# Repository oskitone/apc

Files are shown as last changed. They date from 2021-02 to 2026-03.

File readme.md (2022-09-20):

# APC

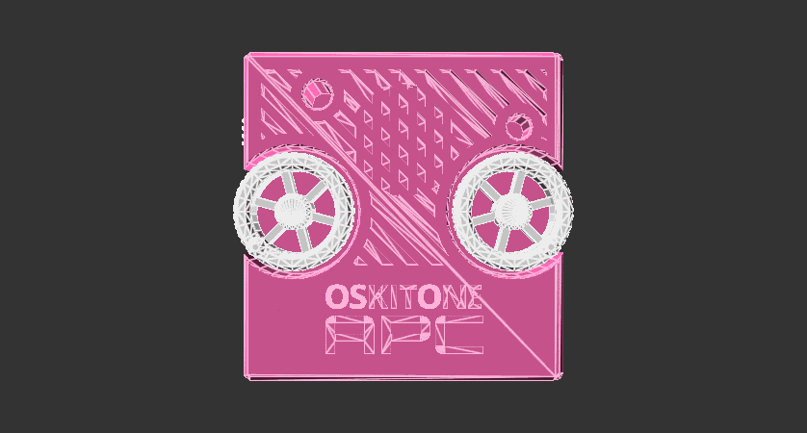
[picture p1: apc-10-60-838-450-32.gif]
APC


A decapitated robot head? An extraterrestrial communicator? A specter summoner?

Nope (and yep!), it's an [APC](https://en.wikipedia.org/wiki/Atari_Punk_Console)!

**Assembly Guide:** [https://oskitone.github.io/apc/](https://oskitone.github.io/apc/)<br />
**Demo:** [https://vimeo.com/518375593](https://vimeo.com/518375593)<br />
**Purchase:** [APC (fully assembled)](https://www.oskitone.com/product/apc), [APC DIY Electronics Kit](https://www.oskitone.com/product/apc-diy-electronics-kit)<br />
**Blog post:** [https://blog.tommy.sh/posts/oskitone-makes-an-atari-punk-console/](https://blog.tommy.sh/posts/oskitone-makes-an-atari-punk-console/)

## KiCad Source

The PCB and its schematic are actually part of [poly555](https://github.com/oskitone/poly555), so head over there to its KiCad project to dig deeper into the electronics. (That the APC is a part of a bigger project may also help to explain why the component numbers start at 100!)

## 3D Models

The APC's 3D-printed models are written in OpenSCAD.

### Changelog

- **September 6, 2021:** Add brim to switch_clutch for better DFM (2d0a1d0), Loosen wheel fit (7e2dab7)
- **February 25, 2021:** Init (8df1dc4)

### Dependencies

Assumes poly555 repo is in a sibling directory. Here's how I've got it:

    \ oskitone
        \ apc
        \ poly555

### Mods

- For pots with flatted D shafts, use `shaft_type = POT_SHAFT_TYPE_FLATTED` in the call to `wheels()` for a better fit.

### Building

STLs are generated with `make_stls.sh`. Run `./make_stls.sh -h` for full flags list.

## License

Designed by Oskitone. Please support future synth projects by purchasing from [Oskitone](https://www.oskitone.com/).

Creative Commons Attribution/Share-Alike, all text above must be included in any redistribution. See license.txt for additional details.

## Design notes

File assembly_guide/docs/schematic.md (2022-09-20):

---
id: schematic
title: Schematic
sidebar_label: Schematic
description: Oskitone APC Schematic
slug: schematic
hide_table_of_contents: true
image: /img/assembly/apc.jpg
---

APC Schematic

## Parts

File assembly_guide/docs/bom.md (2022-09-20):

---
id: bom
title: BOM (Bill of Materials)
sidebar_label: BOM
description: BOM (Bill of Materials)
slug: bom
hide_table_of_contents: true
image: /img/assembly/apc.jpg
---

| Part | Package | Quantity | Value | Marking |
| --- | --- | --- | --- | --- |
| BT101 | Battery snap | 1 | 9v | |
| C101 | Ceramic disc D5.0mm_W2.5mm_P5.00mm  | 1 | .01uF / 10nF | 103 |
| C102 | Ceramic disc D5.0mm_W2.5mm_P5.00mm  | 1 | .1uF | 104 |
| C103 | CP_Radial_D4.0mm_P2.00mm | 1 | 10uF | |
| D101 | LED D5.0mm | 1 | LED | |
| LS101 | Speaker 30mm_36MS30008-PN | 1 | Speaker | |
| R101 | Resistor | 1 | 330 | Orange Orange Brown |
| R102 | Resistor | 1 | 1k | Brown Black Red |
| RV101, RV102 | PTV09 Vertical Pot | 2 | 500k-1M | |
| RV103 | Potentiometer Piher_PT-6-V_Vertical | 1 | 1k | 102 |
| S101 | EG1218 slider switch | 2 | | |
| U101 | DIP-14_W7.62mm_LongPads | 1 | LM556 | |

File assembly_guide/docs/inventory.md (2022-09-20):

---
id: inventory
title: Inventory
sidebar_label: Inventory
description: What you'll need to assembly your APC
slug: inventory
image: /img/assembly/apc.jpg
---

## What You'll Need

- The [Oskitone APC DIY Electronics Kit](https://www.oskitone.com/product/apc-diy-electronics-kit)!
- Soldering iron and solder for electronics
- Wire stripper or cutters
- 9v battery

## Good to have

While not required, it'd be good to have these tools around too.

- Multimeter for debugging
- PCB vice or “helping hands” holder
- “Solder sucker” or desoldering braid
- Patience, patience, patience

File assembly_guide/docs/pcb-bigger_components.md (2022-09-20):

---
id: pcb-bigger_components
title: Bigger components
sidebar_label: 3. Bigger components
description: How to solder the APC's pots, speaker, and IC socket
slug: pcb-bigger_components
image: /img/assembly/apc.jpg
---

:::note
Take your time and make sure the pots and speaker are perfectly flat against the PCB before soldering all of their pins.
:::

Last is the bigger components: pots, speaker, and IC.

1. Push the two **500k pots** ("pot" is short for "potentiometer"!) into their footprints at **RV101** and **RV102**
   1. A trick to get the pot to snap in better is to _gently_ push its mounting tabs inward before popping it onto the PCB.
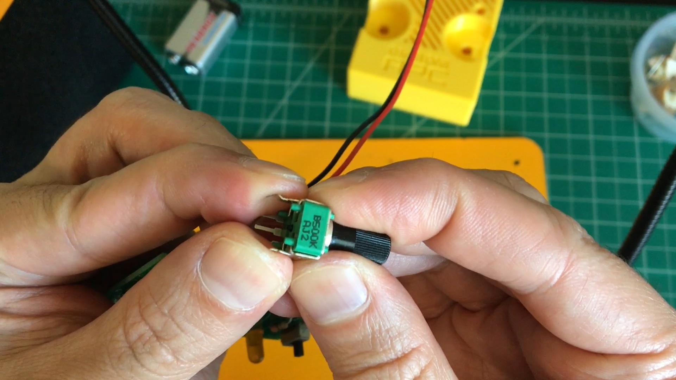
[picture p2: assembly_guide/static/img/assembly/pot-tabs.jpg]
Bending the potentiometer tabs
      
   2. Check that they're flat against the PCB, then solder into place.
   3. You can solder the mounting tabs on the side too, if you want!
2. Fit the **speaker** into **LS101**, matching its **+** and **-** pins to the right holes.
   1. Don't bend its leads! That can break it.
   2. Hold in place and solder. <!-- TODO: advise on technique -->
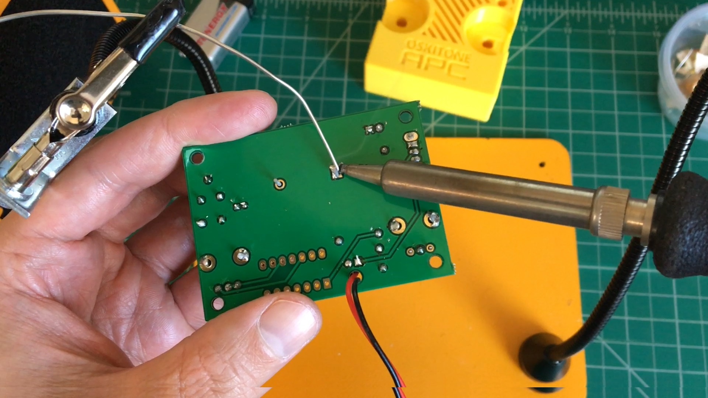
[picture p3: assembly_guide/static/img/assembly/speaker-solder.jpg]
Soldering the APC speaker at LS101
      
   3. Check that the **speaker** is flat against the PCB before continuing.
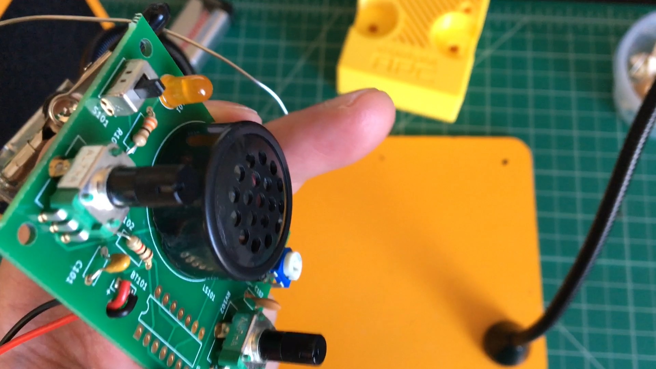
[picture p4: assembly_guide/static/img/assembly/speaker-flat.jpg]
Speaker, flat against PCB
      
3. And the absolute last component to solder is the **IC socket**
   1. Place the **IC socket** into **U101**, matching its little indentation to the footprint.
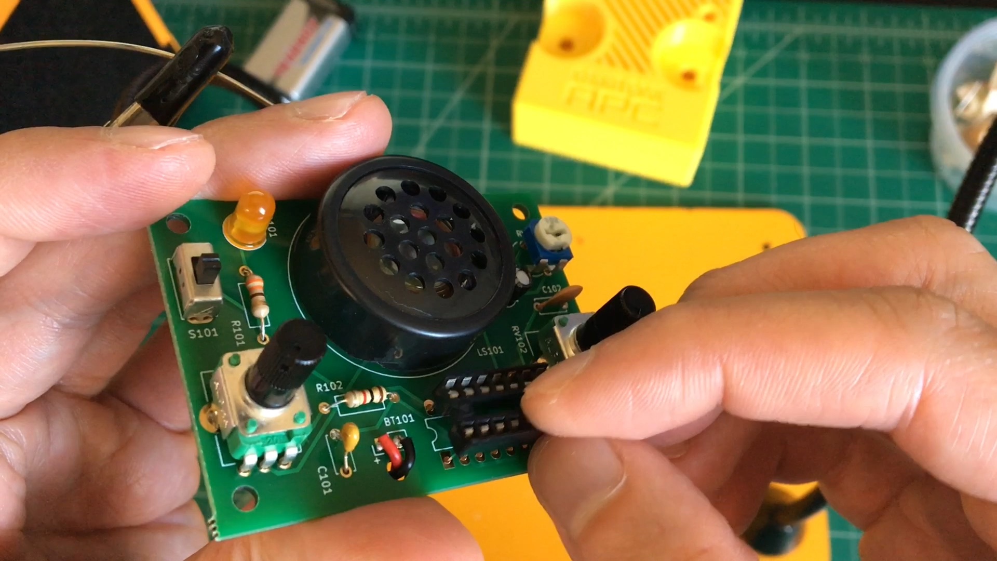
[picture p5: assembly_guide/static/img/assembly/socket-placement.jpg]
Placing the IC socket at U101
      
   2. Hold in place and solder. <!-- TODO: advise on technique -->
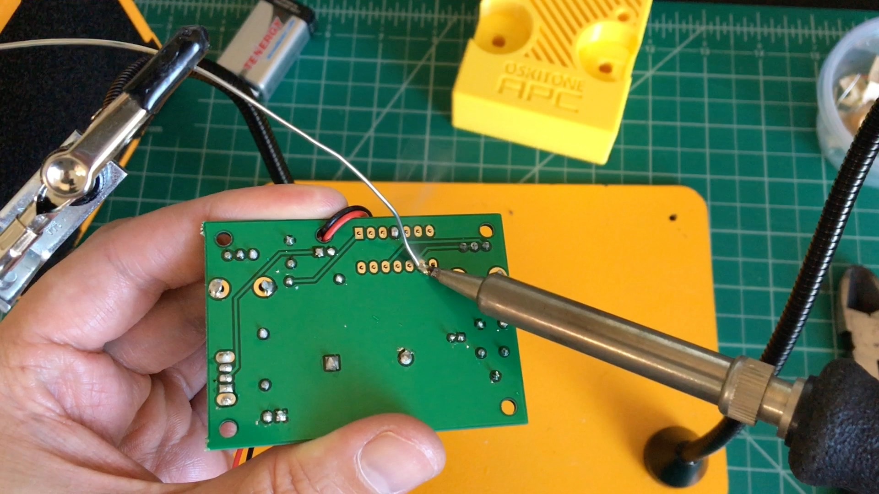
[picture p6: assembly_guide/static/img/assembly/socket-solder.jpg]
Soldering the socket
      
4. With its socket soldered, we can add its **556 chip**.
   1. In order to fit well into its **socket**, the pins of the **556** need to point straight down from the chip's body. You can use a [pin straightener tool](https://www.jameco.com/z/ICS-01-R-Jameco-Benchpro-IC-Pin-Straightener-for-0-300-and-0-600-Wide-ICs_99363.html) or simply bend them against any flat surface. <!-- TODO: advise on technique -->
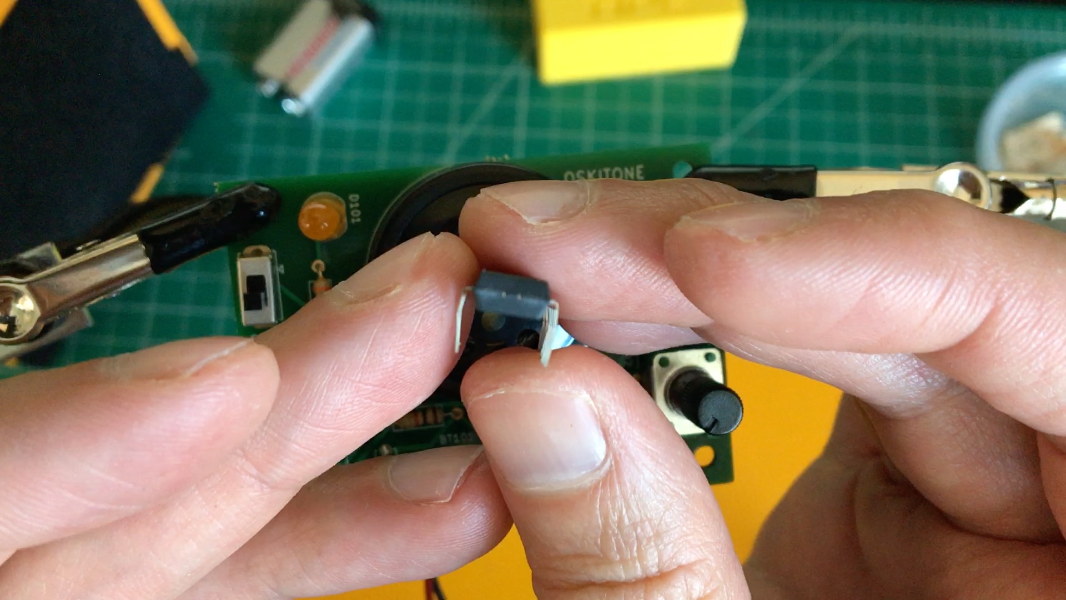
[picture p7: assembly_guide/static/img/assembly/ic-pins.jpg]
The IC chip's pins, straightened
      
   2. Carefully insert the **556 chip** into the **socket** at **U101**, matching its indentation. If its pins don't seem to go in well, try the previous step again.
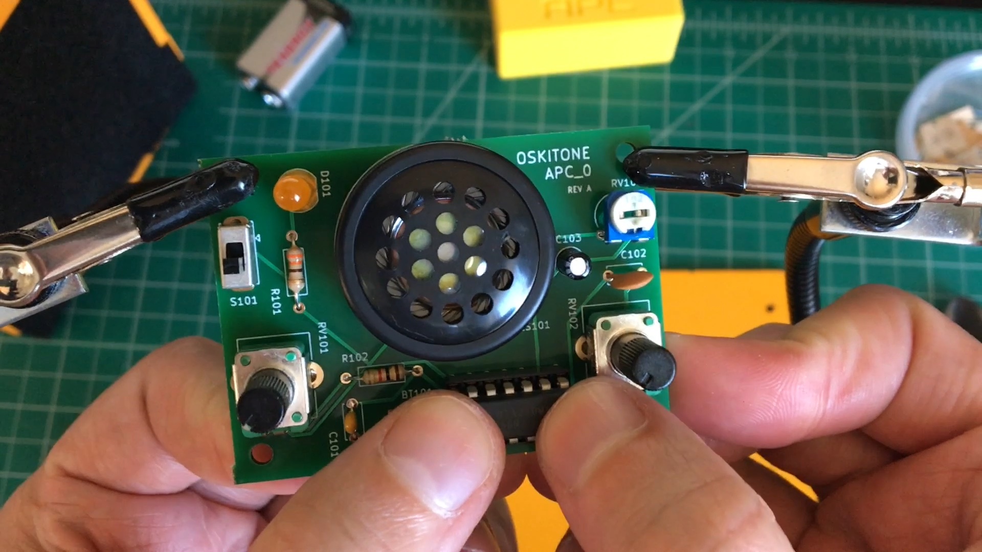
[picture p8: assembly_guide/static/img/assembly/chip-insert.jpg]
556 chip into socket at U101
      

<!-- TODO: consider breaking out test from the rest of the steps -->

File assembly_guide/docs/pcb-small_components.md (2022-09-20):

---
id: pcb-small_components
title: Small components
sidebar_label: 2. Small components
description: Soldering the APC's small components
slug: pcb-small_components
image: /img/assembly/apc.jpg
---

:::note
Take your time and make sure the 1k trim pot is perfectly flat against the PCB before soldering all of its pins.
:::

Next we'll do the remaining small, passive components.

1. There are two small ceramic capacitors:
   1. The one marked _103_ is for **.01uF** (also known as 10nF). It goes to **C101**.
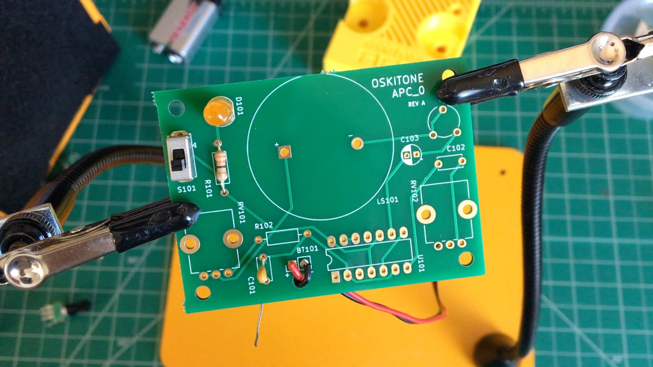
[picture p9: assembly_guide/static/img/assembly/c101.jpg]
.01uF to C101
      
   2. The other's marked _104_, for **.1uF**, and goes to **C102**.
      .1uF to C102
2. The last cap is an electrolytic **10uF** capacitor at **C103**.
   - Match the capacitor's white stripe to the white part of the footprint.
     10uF to C103
3. The remaining resistor is **1k ohms**, colored _Brown Black Red_.
   - Solder to **R102**.
     1k ohms to R102
4. The small, blue **1k trim potentiometer** goes to **RV103**. It's marked _102_. Make sure it's flat against the PCB. <!-- TODO: advise on technique -->
   - 1k trim pot to 102
5. Nothing to test here, but check all solder joints and trim leads before moving on. We're almost done!

<!-- TODO: consider breaking out test from the rest of the steps -->

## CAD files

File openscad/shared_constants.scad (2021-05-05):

// TODO: remove any includes. this file should have no dependencies...
include <battery.scad>;
include <pcb.scad>;

FIXED_LODEF_ROUNDING = 6;
DEFAULT_ROUNDING = $preview ? undef : 24;
HIDEF_ROUNDING = $preview ? undef : 120;

DEFAULT_DFM_LAYER_HEIGHT = .2;
BREAKAWAY_SUPPORT_DEPTH = .5;

DEFAULT_TOLERANCE = .1;

ENCLOSURE_WALL = 2.4;
ENCLOSURE_INNER_WALL = 1.2;
ENCLOSURE_FLOOR_CEILING = 1.8;
ENCLOSURE_INTERNAL_GUTTER = 2;
ENCLOSURE_SIDE_OVEREXPOSURE = 1.4;

ENCLOSURE_GRILL_DEPTH = 6;
ENCLOSURE_GRILL_GUTTER = 4;
ENCLOSURE_GRILL_RING = 3;
ENCLOSURE_GRILL_COVERAGE = .667;

ENCLOSURE_FILLET = 2;
ACCESSORY_FILLET = 1;

ENCLOSURE_WIDTH = PCB_WIDTH
    + ENCLOSURE_INTERNAL_GUTTER * 2
    + ENCLOSURE_WALL * 2;
ENCLOSURE_LENGTH = PCB_LENGTH
    + BATTERY_LENGTH
    + ENCLOSURE_INTERNAL_GUTTER * 3
    + ENCLOSURE_WALL * 2;

LIP_BOX_DEFAULT_LIP_HEIGHT = 3; // TODO: expose
ENCLOSURE_BOTTOM_HEIGHT = max(
    ENCLOSURE_FLOOR_CEILING + LIP_BOX_DEFAULT_LIP_HEIGHT,
    ENCLOSURE_FLOOR_CEILING + PCB_BOTTOM_CLEARANCE
);

SWITCH_CLUTCH_TOP_CLEARANCE = PCB_HEIGHT;
SWITCH_CLUTCH_SLIDE_CLEARANCE = 1.2;

MISC_CLEARANCE = 1;

PCB_X = ENCLOSURE_WALL + ENCLOSURE_INTERNAL_GUTTER;
PCB_Y = ENCLOSURE_WALL + ENCLOSURE_INTERNAL_GUTTER * 2 + BATTERY_LENGTH;
PCB_Z = max(
    ENCLOSURE_BOTTOM_HEIGHT - PCB_HEIGHT,
    ENCLOSURE_FLOOR_CEILING + PCB_BOTTOM_CLEARANCE
);

GRILL_LENGTH = (ENCLOSURE_LENGTH - ENCLOSURE_GRILL_GUTTER * 2)
    * ENCLOSURE_GRILL_COVERAGE;

// This is imperfect:
// 1) The plate is actually longer than grill.
// 2) Wheels may extend beyond grill plate.
BATTERY_FITS_BEYOND_GRILL = (ENCLOSURE_LENGTH - GRILL_LENGTH
    - ENCLOSURE_GRILL_GUTTER * 2) > BATTERY_LENGTH;

ENCLOSURE_HEIGHT =
    max(
        BATTERY_FITS_BEYOND_GRILL
            ? BATTERY_HEIGHT + ENCLOSURE_FLOOR_CEILING + BATTERY_SNAP_CLEARANCE
            : BATTERY_HEIGHT + ENCLOSURE_GRILL_DEPTH + ENCLOSURE_FLOOR_CEILING,
        PCB_Z + PCB_HEIGHT + PTV09A_POT_BASE_HEIGHT + PTV09A_POT_ACTUATOR_HEIGHT
    )
    + ENCLOSURE_FLOOR_CEILING;

ENCLSOURE_TOP_HEIGHT = ENCLOSURE_HEIGHT - ENCLOSURE_BOTTOM_HEIGHT;

Z_PCB_TOP = PCB_Z + PCB_HEIGHT;

DEFAULT_RIB_LENGTH = .8;
DEFAULT_RIB_GUTTER = 1.234;

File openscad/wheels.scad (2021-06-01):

// TODO: extract parts to common repo
use <../../poly555/openscad/lib/basic_shapes.scad>;

include <pcb.scad>;
include <shared_constants.scad>;

WHEEL_DIAMETER = 2 *
    (PCB_X + PCB_POT_POSITIONS[0][0] + ENCLOSURE_SIDE_OVEREXPOSURE);
WHEEL_VERTICAL_EXPOSURE = ENCLOSURE_SIDE_OVEREXPOSURE;
WHEEL_RECESSED_HEIGHT = 13;
WHEEL_HEIGHT = WHEEL_RECESSED_HEIGHT + WHEEL_VERTICAL_EXPOSURE;
WHEEL_DIAMETER_CLEARANCE = 1.2;
WELL_DIAMETER = WHEEL_DIAMETER + WHEEL_DIAMETER_CLEARANCE * 2;
WHEEL_RING = ENCLOSURE_FILLET * 2;

module wheel(
    diameter = WHEEL_DIAMETER,
    height = WHEEL_HEIGHT,
    ring = WHEEL_RING,

    hub_ceiling = ENCLOSURE_FLOOR_CEILING,
    hub_diameter = PTV09A_POT_ACTUATOR_DIAMETER + ENCLOSURE_INNER_WALL * 2,

    brodie_knob_diameter = WHEEL_RING,
    brodie_knob_stilt = 0,
    brodie_knob_count = 1,
    brodie_knob_angle_offset = 0,

    dimple_count = 0,
    dimple_depth = 1,
    dimple_y = undef,

    spokes_count = 6,
    spokes_width = 2,
    spokes_height = WHEEL_HEIGHT * .5,

    chamfer = ENCLOSURE_INNER_WALL - BREAKAWAY_SUPPORT_DEPTH,
    shim_size = .6,
    shim_count = 5,

    shaft_type = POT_SHAFT_TYPE_DEFAULT,

    grip_count = undef,

    test_fit = false,

    color = undef,
    cavity_color = undef,

    tolerance = DEFAULT_TOLERANCE,
    $fn = DEFAULT_ROUNDING
) {
    e = 0.043;

    grip_count = grip_count != undef
        ? grip_count
        : round(
            diameter * PI / (DEFAULT_RIB_LENGTH + DEFAULT_RIB_GUTTER)
        );

    module _hub() {
        if (!test_fit) {
            translate([0, 0, height - ring / 2]) {
                hull() {
                    donut(
                        diameter = hub_diameter,
                        thickness = ring,
                        segments = $preview ? 24 : 36
                    );
                }
            }
        }

        cylinder(
            d = hub_diameter,
            h = height - ring / 2
        );
    }

    module _tire() {
        module _donuts() {
            for (z = [ring / 2, height - ring / 2]) {
                translate([0, 0, z]) {
                    donut(
                        diameter = diameter,
                        thickness = ring,
                        segments = $preview ? 24 : 36
                    );
                }
            }
        }

        difference() {
            union() {
                if (spokes_count > 0) {
                    _donuts();
                } else {
                    hull() {
                        _donuts();
                    }
                }

                translate([0, 0, ring / 2]) {
                    ring(
                        diameter = diameter,
                        height = height - ring,
                        thickness = ring
                    );
                }
            }

            cylinder_grip(
                diameter = diameter,
                height = height,
                count = grip_count,
                size = .8,
                $fn = FIXED_LODEF_ROUNDING
            );
        }
    }

    module _pot_cavity() {
        module _chamfer() {
            translate([0, 0, -e]) {
                cylinder(
                    d1 = PTV09A_POT_ACTUATOR_DIAMETER + tolerance * 2
                        + chamfer * 2,
                    d2 = PTV09A_POT_ACTUATOR_DIAMETER + tolerance * 2
                        - PTV09A_POT_ACTUATOR_D_SHAFT_DEPTH * 2,
                    h = chamfer + PTV09A_POT_ACTUATOR_D_SHAFT_DEPTH + e
                );
            }
        }

        module _grips() {
            cylinder_grip(
                diameter = PTV09A_POT_ACTUATOR_DIAMETER + tolerance * 2,
                height = height - hub_ceiling,
                count = shim_count,
                rotation_offset = 180,
                size = shim_size
            );
        }

        // Cavity is full available height, regardless of actual usage
        pot_cavity_z = height - hub_ceiling
            - PTV09A_POT_BASE_HEIGHT - PTV09A_POT_ACTUATOR_HEIGHT;

        _chamfer();
        difference() {
            translate([0, 0, pot_cavity_z]) {
                pot(
                    show_base = false,
                    diameter_bleed = tolerance,
                    shaft_type = shaft_type,
                    $fn = HIDEF_ROUNDING
                );
            }

            _grips();
        }
    }

    module _spokes() {
        overlap = ring / 2;

        x = spokes_width / -2;
        y = hub_diameter / 2 - overlap;

        length = diameter / 2 - y - ring + overlap;

        for (i = [0 : spokes_count - 1]) {
            rotate([0, 0, (i / spokes_count) * 360]) {
                translate([x, y, 0]) {
                    cube([spokes_width, length, spokes_height]);
                }
            }
        }
    }

    module _brodie_knobs() {
        for (i = [0 : brodie_knob_count - 1]) {
            rotation = brodie_knob_angle_offset + i * (360 / brodie_knob_count);

            rotate([0, 0, rotation]) {
                translate([0, diameter / 2 - brodie_knob_diameter / 2, 0]) {
                    cylinder(
                        h = height + brodie_knob_stilt,
                        d1 = 0,
                        d2 = brodie_knob_diameter
                    );

                    translate([0, 0, height + brodie_knob_stilt]) {
                        sphere(
                            d = brodie_knob_diameter
                        );
                    }
                }
            }
        }
    }

    module _dimple_cavities(dimple_diameter = diameter / 3) {
        assert(
            brodie_knob_count == 0,
            "Dimples and brodie knobs can't be used together. Set brodie_knob_count to 0."
        );

        assert(
            spokes_count == 0,
            "Dimples and spokes can't be used together. Set spokes_count to 0."
        );

        for (i = [0 : dimple_count - 1]) {
            y = dimple_y != undef
                ? dimple_y
                : diameter / 2 - dimple_diameter / 2 - ring / 2;
            rotation = i * (360 / dimple_count);

            rotate([0, 0, rotation]) {
                translate([0, y, height - dimple_depth]) {
                    cylinder(
                        h = dimple_depth + e,
                        d = dimple_diameter
                    );
                }
            }
        }
    }

    difference() {
        color(color) {
            union() {
                if (spokes_count > 0) {
                    _hub();
                }

                if (!test_fit) {
                    _tire();

                    if (spokes_count > 0) {
                        _spokes();
                    }

                    if (brodie_knob_count > 0) {
                        _brodie_knobs();
                    }
                }
            }
        }

        color(cavity_color) {
            _pot_cavity();

            if (dimple_count > 0) {
                _dimple_cavities();
            }
        }
    }
}

function slice(list, start = 0, end) =
    end == 0
        ? []
        : [for (i = [start : (end == undef ? len(list) : end) - 1]) list[i]]
;

module wheels(
    diameter = WHEEL_DIAMETER,
    height = WHEEL_HEIGHT,
    shaft_type = POT_SHAFT_TYPE_DEFAULT,
    y = 0,
    z = 0,
    test_fit = false,
    count = undef
) {
    e = .04321;

    for (xy = slice(PCB_POT_POSITIONS, 0, count)) {
        translate([
            ENCLOSURE_WALL + ENCLOSURE_INTERNAL_GUTTER + xy.x,
            y + xy.y,
            z
        ]) {
            wheel(
                shaft_type = shaft_type,
                test_fit = test_fit
            );
        };
    }
}

// shim .5 * 3 is still good
// .6 * 3 could be good w/ bigger chamfer
// .6 * 4 feels even better
// 5 shims is whatever and 6 is too many
// .8 is too big, regardless

// all of these work
/* shim_sizes = [.5, .6];
shim_counts = [3, 5];

plot = 7.8;

for (i = [0 : len(shim_sizes) - 1]) {
    for (ii = [0 : len(shim_counts) - 1]) {
        shim_size = shim_sizes[i];
        shim_count = shim_counts[ii];

        is_needle = shim_size == .5 && shim_count == 3;

        translate([i * plot, ii * plot, 0]) {
            color(is_needle ? "red" : undef) {
                wheel(
                    height = 8,
                    shim_size = shim_size,
                    shim_count = shim_count,
                    test_fit = true,
                    shaft_type = POT_SHAFT_TYPE_SPLINED,
                    chamfer = .8
                );
            }
        }
    }
} */

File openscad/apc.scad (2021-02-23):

include <battery.scad>;
include <cross_section.scad>;
include <enclosure.scad>;
include <switch_clutch.scad>;
include <wheels.scad>;

module apc(
    show_enclosure_top = true,
    show_enclosure_bottom = true,

    show_pcb = true,
    show_wheels = true,
    show_switch_clutch = true,
    show_battery = true,

    show_dfm = true,

    wheels_count = undef,

    enclosure_color = "hotpink",
    wheels_color = "white",
    switch_clutch_color = "white",

    switch_position = round($t),
    enclosure_bottom_position = 0 // abs($t - .5) * 2
) {
    e = .0123;

    color(enclosure_color) {
        if (show_enclosure_bottom) {
            enclosure_bottom(
                enclosure_bottom_position = enclosure_bottom_position
            );
        }

        if (show_enclosure_top) {
            enclosure_top(
                show_dfm = show_dfm
            );
        }
    }

    if (show_pcb) {
        translate([
            ENCLOSURE_WALL + ENCLOSURE_INTERNAL_GUTTER,
            ENCLOSURE_LENGTH - ENCLOSURE_WALL - ENCLOSURE_INTERNAL_GUTTER
                - PCB_LENGTH,
            PCB_Z - e
        ]) {
            # pcb(
                show_board = true,
                show_speaker = true,
                show_pots = true,
                show_led = true,
                show_switch = true,
                show_volume_pot = true,
                switch_position = switch_position
            );
        }
    }

    color (wheels_color) {
        if (show_wheels) {
            wheels(
                diameter = WHEEL_DIAMETER,
                height = WHEEL_HEIGHT,
                y = PCB_Y,
                z = ENCLOSURE_HEIGHT - WHEEL_HEIGHT + WHEEL_VERTICAL_EXPOSURE
                    - e,
                count = wheels_count
            );
        }
    }

    if (show_switch_clutch) {
        color(switch_clutch_color) {
            switch_clutch(
                position = switch_position,
                show_dfm = show_dfm
            );
        }
    }

    if (show_battery) {
        translate([
            ENCLOSURE_WALL + ENCLOSURE_INTERNAL_GUTTER,
            ENCLOSURE_WALL + ENCLOSURE_INTERNAL_GUTTER,
            ENCLOSURE_FLOOR_CEILING
        ]) {
            battery();
        }
    }
}

SHOW_ENCLOSURE_TOP = true;
SHOW_ENCLOSURE_BOTTOM = true;
SHOW_PCB = true;
SHOW_WHEELS = true;
SHOW_SWITCH_CLUTCH = true;
SHOW_BATTERY = true;
SHOW_DFM = false;

WHEELS_COUNT = undef;
CROSS_SECTION = undef;

FLIP_VERTICALLY = false;
CENTER = false;

position = CENTER
    ? [
        ENCLOSURE_WIDTH / -2,
        ENCLOSURE_LENGTH / -2,
        ENCLOSURE_HEIGHT / -2
    ] : [0, 0, 0];
rotation = FLIP_VERTICALLY ? [0, 180, 0] : [0, 0, 0];

translate(position) rotate(rotation) {
    intersection() {
        apc(
            show_enclosure_top = SHOW_ENCLOSURE_TOP,
            show_enclosure_bottom = SHOW_ENCLOSURE_BOTTOM,
            show_pcb = SHOW_PCB,
            show_wheels = SHOW_WHEELS,
            show_switch_clutch = SHOW_SWITCH_CLUTCH,
            show_battery = SHOW_BATTERY,
            show_dfm = SHOW_DFM,
            wheels_count = WHEELS_COUNT
        );

        if (CROSS_SECTION) {
            cross_section(CROSS_SECTION);
        }
    }
}

echo(str("ENCLOSURE: ", ENCLOSURE_WIDTH, " x ", ENCLOSURE_LENGTH, " x ", ENCLOSURE_HEIGHT));
echo(str("WHEELS: ", WHEEL_DIAMETER, " diameter, ", WHEEL_HEIGHT, " height"));

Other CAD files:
openscad/assembly.scad
openscad/battery.scad
openscad/cross_section.scad
openscad/enclosure.scad
openscad/floating_hole_cavity.scad
openscad/pcb.scad
openscad/rib_cavities.scad
openscad/switch_clutch.scad

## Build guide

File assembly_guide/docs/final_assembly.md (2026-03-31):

---
id: final_assembly
title: Final Assembly
sidebar_label: Final Assembly
description: Final assembly steps for the APC
slug: final_assembly
image: /img/assembly/apc.jpg
---

## Steps

1. Insert **switch clutch** into its cavity in the **enclosure top**.
   - It will fit in with room to slide back and forth.
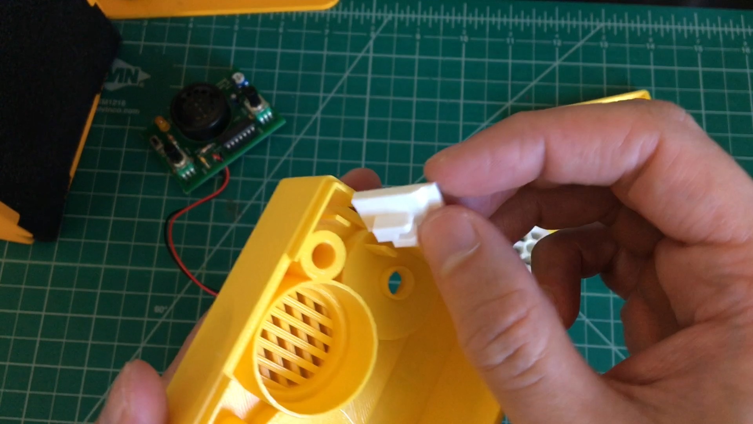
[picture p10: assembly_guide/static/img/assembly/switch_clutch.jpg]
Insert switch clutch
     
2. Insert **PCB** into **enclosure top**.
   - It should fit perfectly without too much force. Wiggle the **switch clutch** around if it's not in the right place.
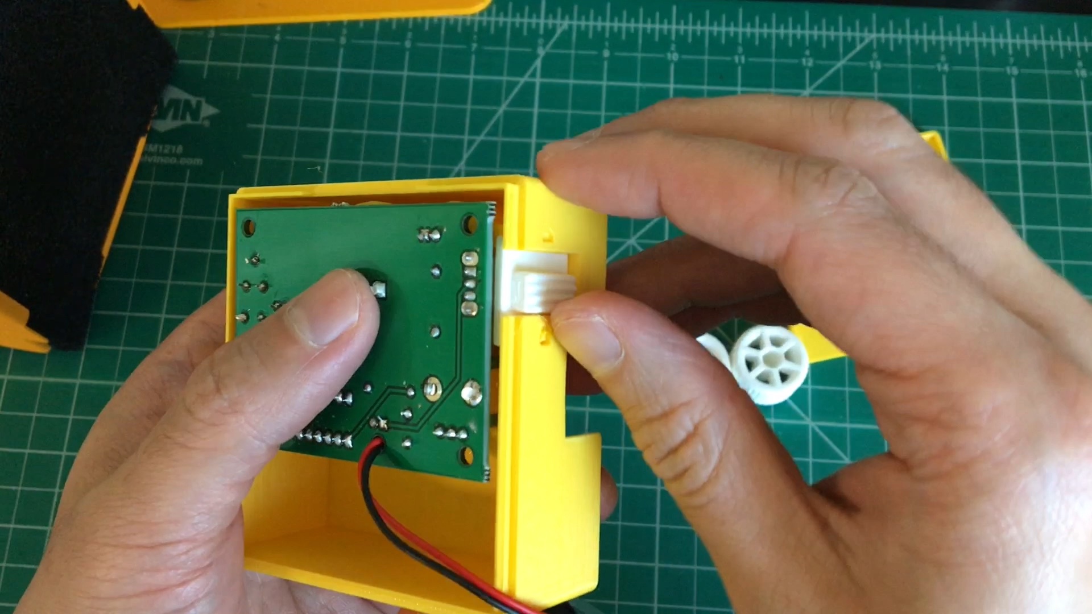
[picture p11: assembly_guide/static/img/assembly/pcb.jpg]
Insert PCB
     
3. Insert **battery** into its spot in the **enclosure bottom**.
   - Its wires can be tucked under the PCB
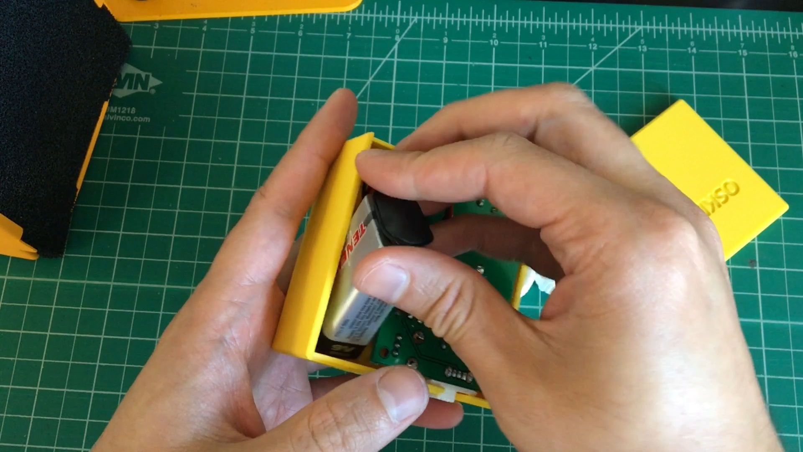
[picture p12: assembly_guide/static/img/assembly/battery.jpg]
Insert battery
     
4. Slide **enclosure bottom** onto **enclosure top**.
   - This will hold the battery and **PCB** in place.
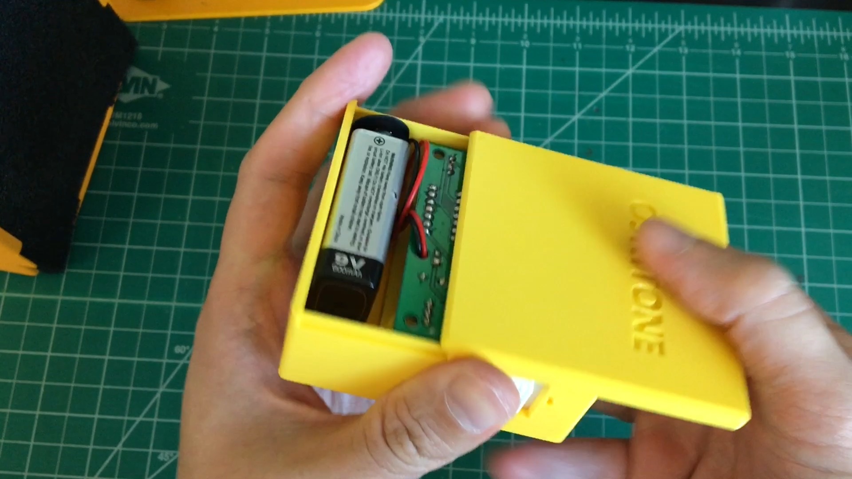
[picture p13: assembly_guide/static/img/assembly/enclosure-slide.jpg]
Slide enclosure halves together
     
   - **Troubleshooting: enclosure halves are getting stuck and can't slide together all the way**
     - Make sure the **PCB** is pushed into the enclosure top all the way. Then, when sliding the enclosure bottom on, try bending it slightly _out_ where its rails meet the **PCB**.
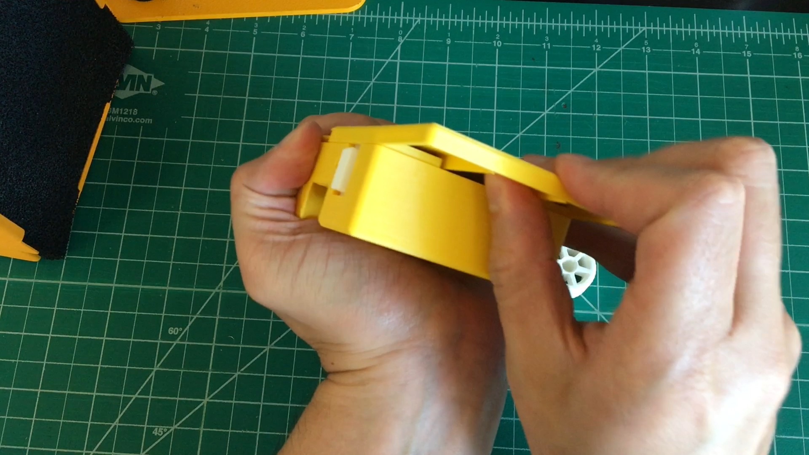
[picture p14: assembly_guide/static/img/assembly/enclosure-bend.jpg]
Bend enclosure top up if necessary
       
       <!-- TODO: annotate image -->
5. Fit **wheels** into their cavity wells on the **enclosure top** and onto the pot shafts.
   - They should also fit perfectly without too much force.
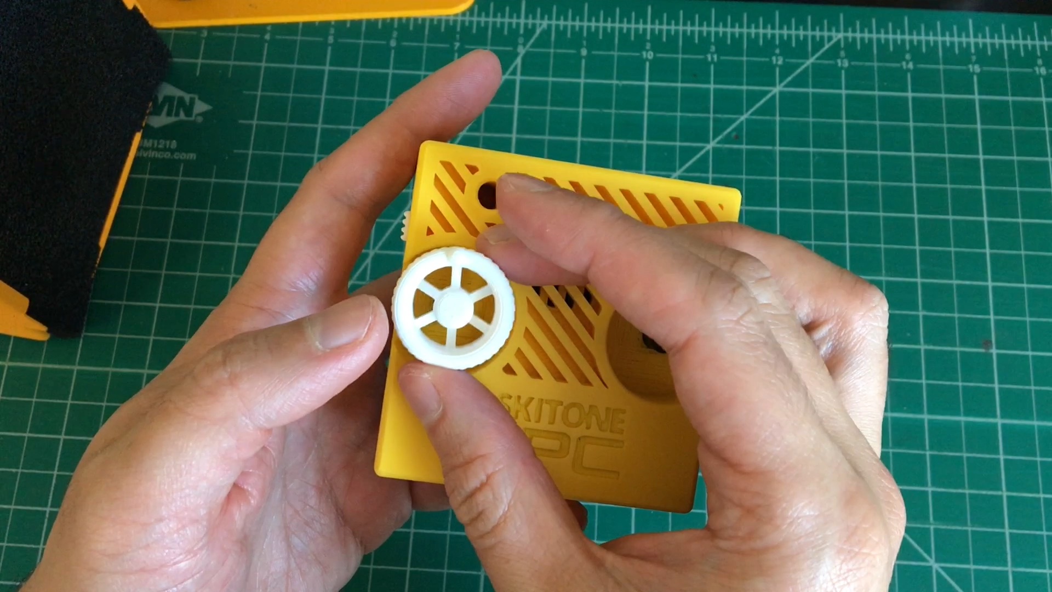
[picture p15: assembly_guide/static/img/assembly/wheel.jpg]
Add wheels
     
   - **Troubleshooting: Wheels aren't popping on all the way:**
     - Use a butter knife (or similar flat tool like a flathead screwdriver or paint spatula) to pop the **wheel** off its pot, then press it back on. Sometimes it just takes another try!

You're done! Excellent work!

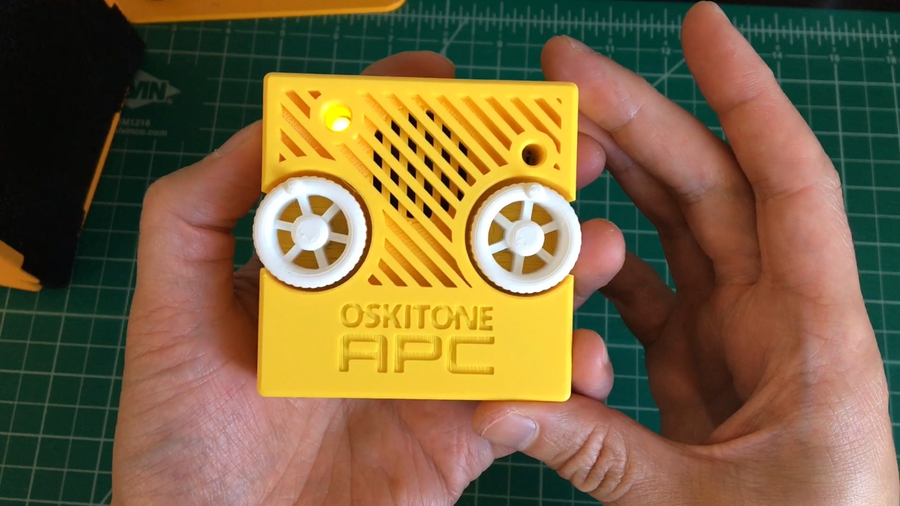
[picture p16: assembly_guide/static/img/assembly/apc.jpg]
An assembled Oskitone APC


## What's next

### Feedback

When you can, please [let me know](https://www.oskitone.com/contact) how it went for you:

- **What did you like?** Did you have fun?!
- Not including printing time, about **how long did it take?**
- **How'd the kit show up?** Were there any parts missing or damaged? Or any **problems with the instructions**?

I act and rely on customers' feedback to make the next products even better. Even just knowing that you got it done successfully is valuable feedback, so I do want to hear from you. Thank you so much!

### Share your make

Do you like your APC? I'd love to have you share that!

- If you 3D-printed it at home, share your make on the [Printables](https://www.printables.com/model/224313-apc-atari-punk-console) or [Thingiverse](https://www.thingiverse.com/thing:7326507) page where you downloaded the models. It's a good signal to other potential makers to see successful makes.
- Tell your friends, post on social, etc. You know the deal! Tag `@oskitone` for extra good luck.

### Follow along

I run an informal [email list](https://www.oskitone.com/mailing-list) to update folks on projects, notify when new products hit the store, and get early feedback and share ideas. If you're interested in what's next with Oskitone, it's the best way to stay updated.

<iframe
  scrolling="no"
  style={{width: "100%", height: "135px", border: "none"}}
  src="https://buttondown.com/oskitone?as_embed=true"
></iframe>

Powered by [Buttondown](https://buttondown.com/refer/oskitone). Read previous emails in the archive [here](https://buttondown.com/oskitone/archive/).

And, of course, follow [@oskitone on Instagram](https://www.instagram.com/oskitone).

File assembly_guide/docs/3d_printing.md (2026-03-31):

---
id: 3d-printing
title: 3D-Printing
sidebar_label: 3D-Printing
description: How to 3D-print your APC's parts
slug: 3d-printing
image: /img/assembly/apc.jpg
---

:::note
If you bought a kit with 3D-printed parts included, you can skip this step.
:::

:::info
If you don't have access to a 3D printer and can't get the parts made, you can still assemble the kit's electronics without them. Continue on to the next step.
:::

## Models

Download STLs of the models from [Printables](https://www.printables.com/model/224313-apc-atari-punk-console) or [Thingiverse](https://www.thingiverse.com/thing:7326507).

There are four files to print:

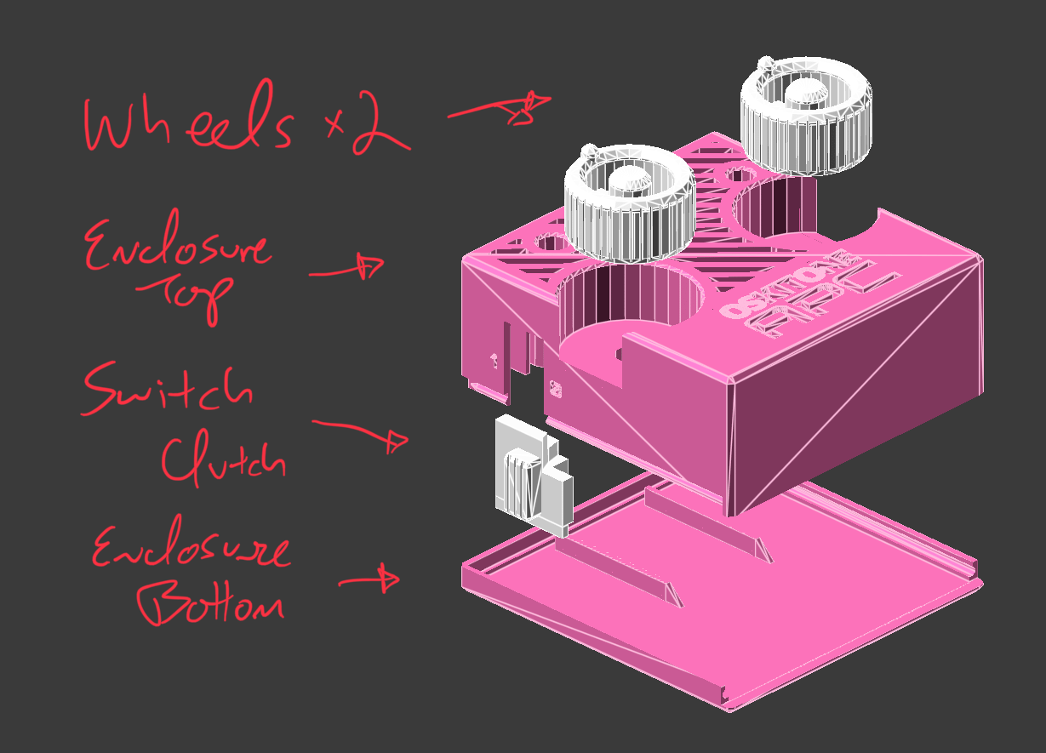
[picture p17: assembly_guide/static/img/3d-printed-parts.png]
Exploded CAD view of the four models


| Part | Count | Layer Height | Supports? | Estimated Time |
| --- | ----- | --- | --- | --- |
| Wheels | 2 | .2mm | No | 1hr 8min |
| Enclosure top | 1 | .2mm | No | 4hr |
| Switch clutch | 1 | .2mm | No | 20min |
| Enclosure bottom | 1 | .2mm | No | 48min |

## Notes

- Models assume Fused Deposition Modeling with a standard .4mm nozzle. Using a bigger nozzle will likely result in a loss of detail and possibly missing internal walls.
- The 3D-printed parts were designed using PLA. Other filament types like ABS are not recommended and will likely have fit or tolerance issues. (If you find that you need to drill or file your prints, that's a good sign there'll be other problems too.)
- They also don't need supports and should already be rotated to the correct orientation for printing.
- Watch the first couple layers of the enclosure pieces while printing, especially around the text engravings &mdash; if you see bad adhesion, stop the print to remedy the situation and start again.
- If the prints aren't fitting together well, check to see that the corners aren't bulging. See if your slicer has settings for "coasting" or "linear advance."
- The switch clutch has two narrow support walls that will [break off when it's done printing](https://twitter.com/oskitone/status/1367957529406316545).

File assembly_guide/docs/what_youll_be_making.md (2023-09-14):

---
id: what-youll-be-making
title: Oskitone APC Assembly Guide
sidebar_label: What You'll Be Making
description: How to solder and assemble the Oskitone APC Electronics Kit
slug: /
image: /img/assembly/apc.jpg
---

APC

A decapitated robot head? An extraterrestrial communicator? A specter summoner?

Nope (and yep!), it's an [APC](https://en.wikipedia.org/wiki/Atari_Punk_Console)!

**Demo:** [https://vimeo.com/518375593](https://vimeo.com/518375593)<br />
**Purchase:** [APC (fully assembled)](https://www.oskitone.com/product/apc), [APC DIY Electronics Kit](https://www.oskitone.com/product/apc-diy-electronics-kit)<br />
**Blog post:** [https://blog.tommy.sh/posts/oskitone-makes-an-atari-punk-console/](https://blog.tommy.sh/posts/oskitone-makes-an-atari-punk-console/)<br />
**Source code:** [https://github.com/oskitone/apc](https://github.com/oskitone/apc)

## Um, WHAT

The APC (Atari Punk Console) is some kind of noise toy. Its circuit was originally described in the early 80s but it was such a hit that it's become something of a go-to project for folks new to electronics and soldering! There are _tons_ of versions of it but they all share the same basic parts.

An assembled Oskitone APC

The Oskitone APC is the function of the classic circuit in an Oskitone form. It's not very useful or musically pleasant, but it's fun!

I wrote a lot of words about this particular Atari Punk Console here, its design and history with the POLY555, and some other stuff here: [Oskitone Makes an Atari Punk Console](https://blog.tommy.sh/posts/oskitone-makes-an-atari-punk-console/)

<!-- ![TODO: image of APC w/ labelled controls](https://dummyimage.com/1920x1080/000/fff) -->

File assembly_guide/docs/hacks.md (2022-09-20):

---
id: hacks
title: Hacks
sidebar_label: Hacks
description: Different hacks you can try on the APC
slug: hacks
image: /img/assembly/apc.jpg
---

The Oskitone APC wants to be hacked and modified!

Here are some ideas:

- Add a quick-and-dirty interrupt button by wiring a switch between the battery's positive wire and the PCB "**+**" pad. [It's fun](https://www.instagram.com/p/CMz4yeIjg4J/)!
- Want an output jack? Try connecting the speaker pins to a 1/8" or 1/4" jack, but be careful about connecting directly to sensitive equipment &mdash; the output voltage is the battery's 9v, which is much higher than a typical line-level 1v!
  - [There _is_ a way to make an Atari Punk Console have line-level output](https://compiler.kaustic.net/machines/apc.html), but it doesn't account for a built-in speaker, so you may have to sacrifice it.

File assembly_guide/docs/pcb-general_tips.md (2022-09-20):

---
id: general-tips
title: PCB general tips
description: Things to keep in mind as you solder your APC.
sidebar_label: General tips
image: /img/assembly/apc.jpg
slug: /general-tips
---

:::note
Take your time and be patient! If you run into a problem, try to keep a cool head and refer to the [PCB troubleshooting](pcb-troubleshooting.md) section. If your problem remains unfixed and you can't figure it out, [please _email_ me to let me know](https://www.oskitone.com/contact)! I'll do my best to help you, and your feedback will help improve the guide and other future Oskitone designs.
:::

<iframe src="https://player.vimeo.com/video/647507121?h=e02ab3c510" width="640" height="360" frameborder="0" allow="autoplay; fullscreen; picture-in-picture" allowfullscreen></iframe>

## General tips

- **Component colors**<br />
  This guide's components' brands and body colors (and even the PCB color itself) may look different from yours, and that's okay! What's important is that the part types and values are in the right spots.
- **Resistors are labeled with colors, capacitors with numbers**<br />
  Resistors' values are marked as colored bands on their body. Ceramic capacitors use a number system to denote their value.
- **Ceramic and electrolytic capacitors**<br />
  There are two kinds of “caps” used in this kit. Ceramic capacitors are small, circular, and have no polarity; they can be placed in either direction. Electrolytic caps are bigger, cylindrical, and have marked +/- polarities.
- **IC chip is static-sensitive**<br />
  The included IC chip can be damaged by static electricity. Leave it in its packaging until ready to install. Before handling, discharge any static electricity on your body by touching a large piece of metal. You can even use an anti-static mat and/or wrist strap for extra caution.
- **IC in sockets**<br />
  The IC chip comes with a corresponding socket with the same number of pins. You will solder the socket to the PCB, not the chip itself. This prevents overheating the IC with the soldering iron and makes it easier to switch a faulty one out.
- **Component polarities**<br />
  LEDs, batteries, and electrolytic capacitors have positive and negative leads. Where applicable, the PCB will be labeled where each lead goes or a component outline to denote orientation.
- **IC orientation**<br />
  The IC chip also has an orientation, marked by a notch at its top. Make sure these line up when soldering the sockets and again when inserting the chips. A chip can be permanently damaged if inserted incorrectly!
- **Get tricky/sticky with short-lead components**<br />
  Components with short leads can be hard to get to stay on the PCB, because you can't really bend their leads to get them to stay put. But there are tricks! Try using tape or "Blu-Tack" adhesive to hold them. Or clip the solder into your "holding hands", and try bringing the _board to the solder_ (instead of the typical reverse of solder to board).

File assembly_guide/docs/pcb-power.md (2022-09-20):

---
id: pcb-power
title: Power up
sidebar_label: 1. Power up
description: How to get power to the APC PCB
slug: pcb-power
image: /img/assembly/apc.jpg
---

:::info
This guide's components' brands and body colors (and even the PCB color itself) may look different from yours, and that's okay! What's important is that the part types and values are in the right spots.
:::

:::note
Take your time and make sure the LED and switch are perfectly flat against the PCB before soldering all of their pins.
:::

First, we'll get power to the board and make sure our battery is working.

1. Find the **330 ohm resistor**; its color bands are _Orange Orange Brown_. Solder it into **R101**.
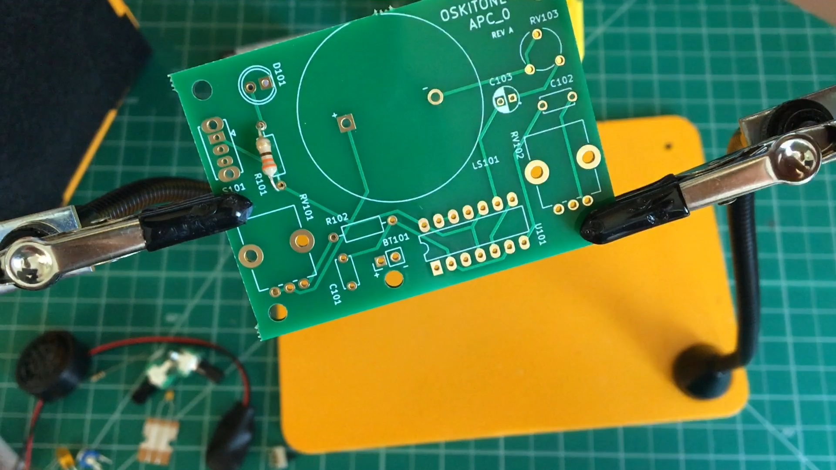
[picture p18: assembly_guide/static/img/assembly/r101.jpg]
330 resistor to R101
   - 
2. The **LED** goes to **D101**.
   1. Note that the footprint on the PCB is a circle with one flat side. Insert the **LED** so its flat side matches that footprint.
   2. Hold in place and solder. Make sure it's flat against the PCB. <!-- TODO: advise on technique -->
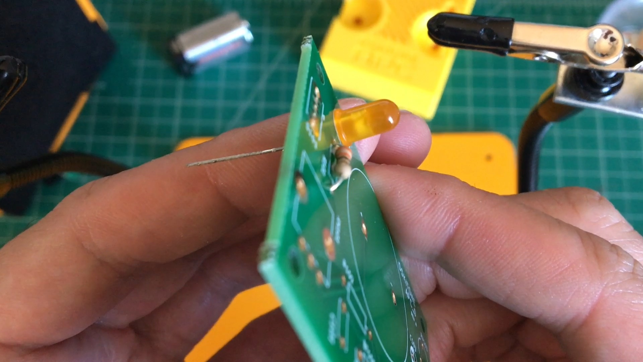
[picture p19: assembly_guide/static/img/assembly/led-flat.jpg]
LED, perfectly flat against PCB, at D101
      
3. The **slider switch** goes to **S101**.
   1. It doesn't have polarity and can go in either direction, but, just like the **LED**, it does need to be perfectly flat against the PCB.
   2. Confirm it's flat before soldering soldering all of its pads. <!-- TODO: advise on technique -->
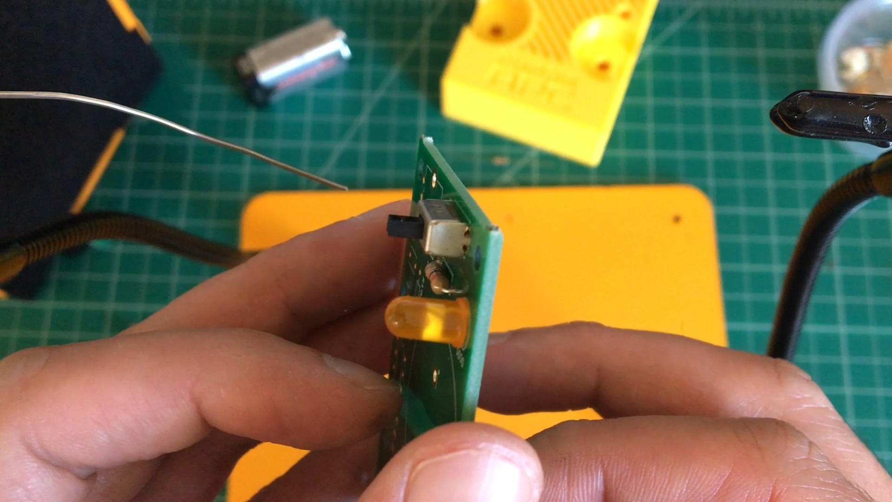
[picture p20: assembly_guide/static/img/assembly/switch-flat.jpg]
Switch, perfectly flat against PCB, at S101
      
4. Next up is the **9v battery snap**.
   1. Feed its wires through the hole by **BT101**. This acts as a stress relief, preventing strain at the solder joints whenever you replace the battery.
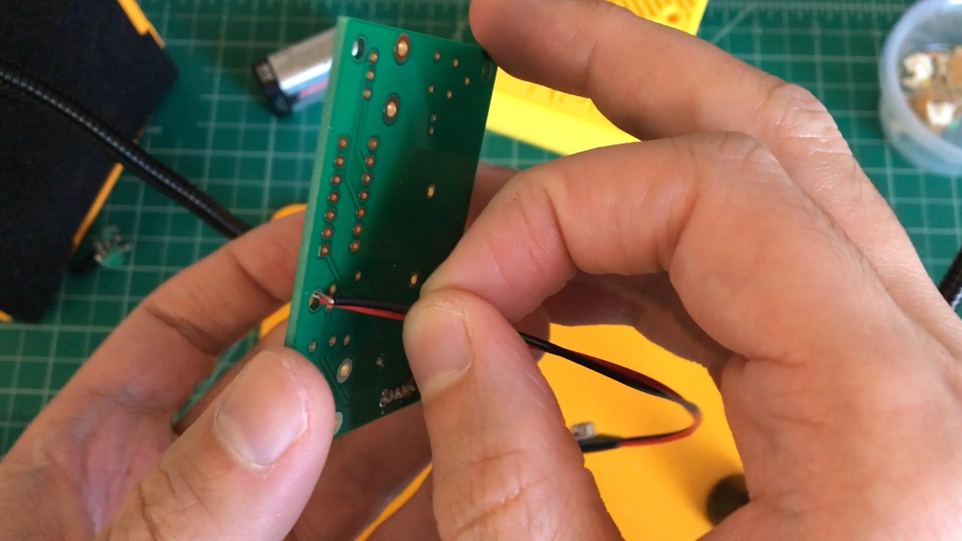
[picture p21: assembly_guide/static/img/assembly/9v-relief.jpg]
9v snap wires in their relief hole
      
   2. Insert and solder wires into place: red to **+** and black to **-**
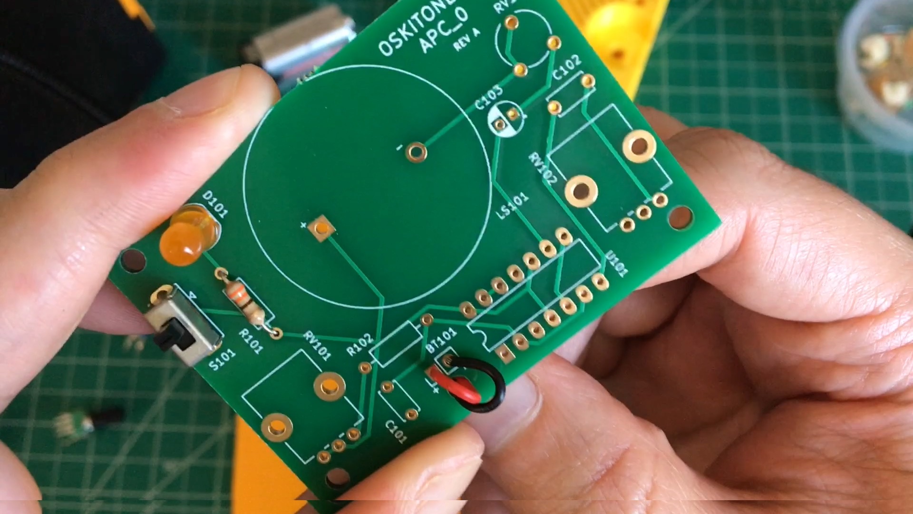
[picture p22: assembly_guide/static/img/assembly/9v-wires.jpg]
9v snap wires in place at BT101
      
5. **Test it!**
   1. Connect a **battery** to the **9v snap**, and slide the **switch** back and forth. You should see the **LED** turn on and off. Nice!
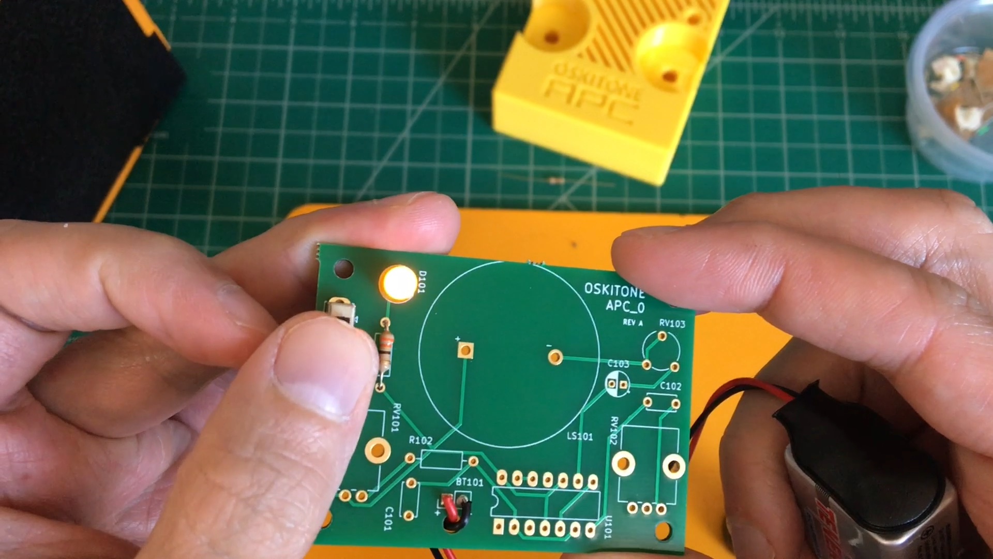
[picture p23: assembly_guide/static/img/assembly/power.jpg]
Testing power
      
   2. If you don't, don't worry; it's just time to debug. _Don't move on to the next step until you've got this working._
      - Check all your solder joints.
      - Verify **LED** is placed correctly and matches its footprint.
      - Is the **battery** dead?
      - Are the **battery** wires in the right spots?
6. Trim leads if you haven't already, and remove the **battery** before continuing.

<!-- TODO: consider breaking out test from the rest of the steps -->

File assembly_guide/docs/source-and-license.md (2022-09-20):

---
id: source-and-license
title: "Source and License"
description: The APC is open-source hardware.
sidebar_label: Source and License
image: /img/assembly/apc.jpg
---

## Source

The APC is open-source hardware.

[https://github.com/oskitone/apc](https://github.com/oskitone/apc)

## License

> Designed by Oskitone. Please support future synth projects by purchasing from [Oskitone](https://www.oskitone.com/).
>
> Creative Commons Attribution/Share-Alike, all text above must be included in any redistribution. See license.txt for additional details.

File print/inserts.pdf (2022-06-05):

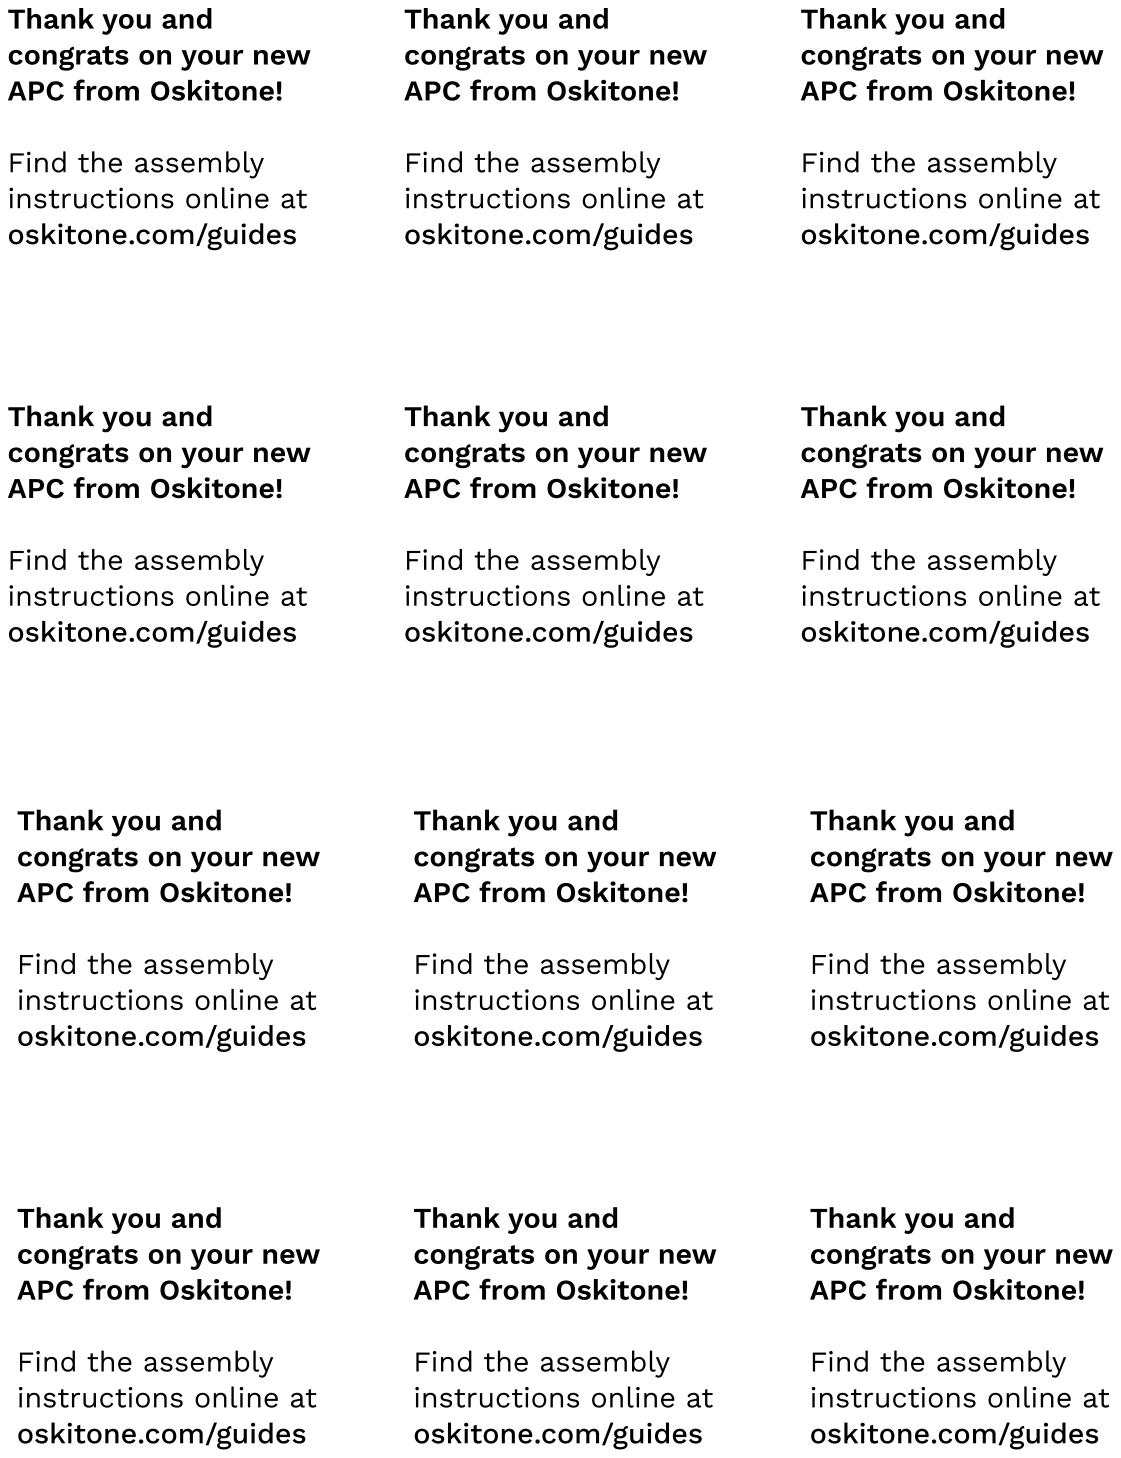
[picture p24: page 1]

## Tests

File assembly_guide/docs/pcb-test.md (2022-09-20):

---
id: pcb-test
title: Test
sidebar_label: 4. Test
description: Testing the APC PCB after soldering
slug: pcb-test
image: /img/assembly/apc.jpg
---

All done soldering! Let's test it.

1.  Reconnect the **battery**.
2.  Slide power **switch**.
3.  Use a screwdriver to adjust the volume at **RV103** and the two bigger **potentiometers** until you hear noises coming out of the **speaker**.
    - If you hear noise, congrats! You successfully soldered your **Oskitone APC**!
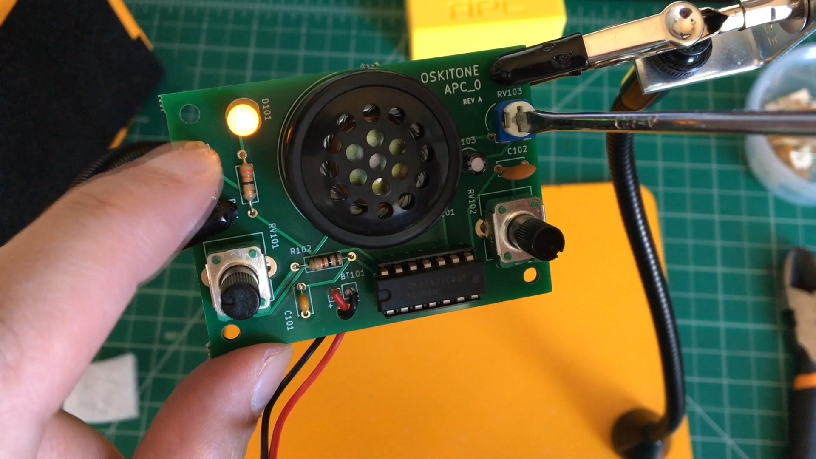
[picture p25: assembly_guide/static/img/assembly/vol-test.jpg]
A successfully soldered and working Oskitone APC
      
4.  If not, don't worry. It's time to debug:
    - Check all your solder joints again
    - Are the components with polarity (**+** and **-** sides) right?
    - Is the **556 chip** pushed all they way into the socket? And none of its legs are bent?
    - Try using a multimeter to confirm power and ground are at all the pins you'd expect, referring to the schematic.

<!-- TODO: consider breaking out test from the rest of the steps -->

Next, let's get the soldered PCB assembled into its enclosure...

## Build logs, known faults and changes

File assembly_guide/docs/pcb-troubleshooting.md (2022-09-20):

---
id: pcb-troubleshooting
title: PCB troubleshooting
description: Common problems that come up when soldering the APC PCB.
sidebar_label: PCB troubleshooting
image: /img/assembly/apc.jpg
slug: /pcb-troubleshooting
---

## General tips

Any of these problems can cause a variety of "just not working right" errors in a circuit. Familiarize yourself with these troubleshooting checks and do them regularly.

- Turn the PCB over and check all solder joints. A majority of problems are caused by insufficient or errant soldering. Familiarize yourself with what a good joint looks like in the [Adafruit Guide To Excellent Soldering](https://learn.adafruit.com/adafruit-guide-excellent-soldering).
- Is the chip in the right orientation? It will have a notch/dimple that should match the footprint outline on the PCB.
- Does the battery have enough power? It should measure 9 volts. Try replacing with a fresh battery and see if that solves your issue.

## Specific issues

- If there’s buzzing, check for any metal scraps stuck to the speaker.

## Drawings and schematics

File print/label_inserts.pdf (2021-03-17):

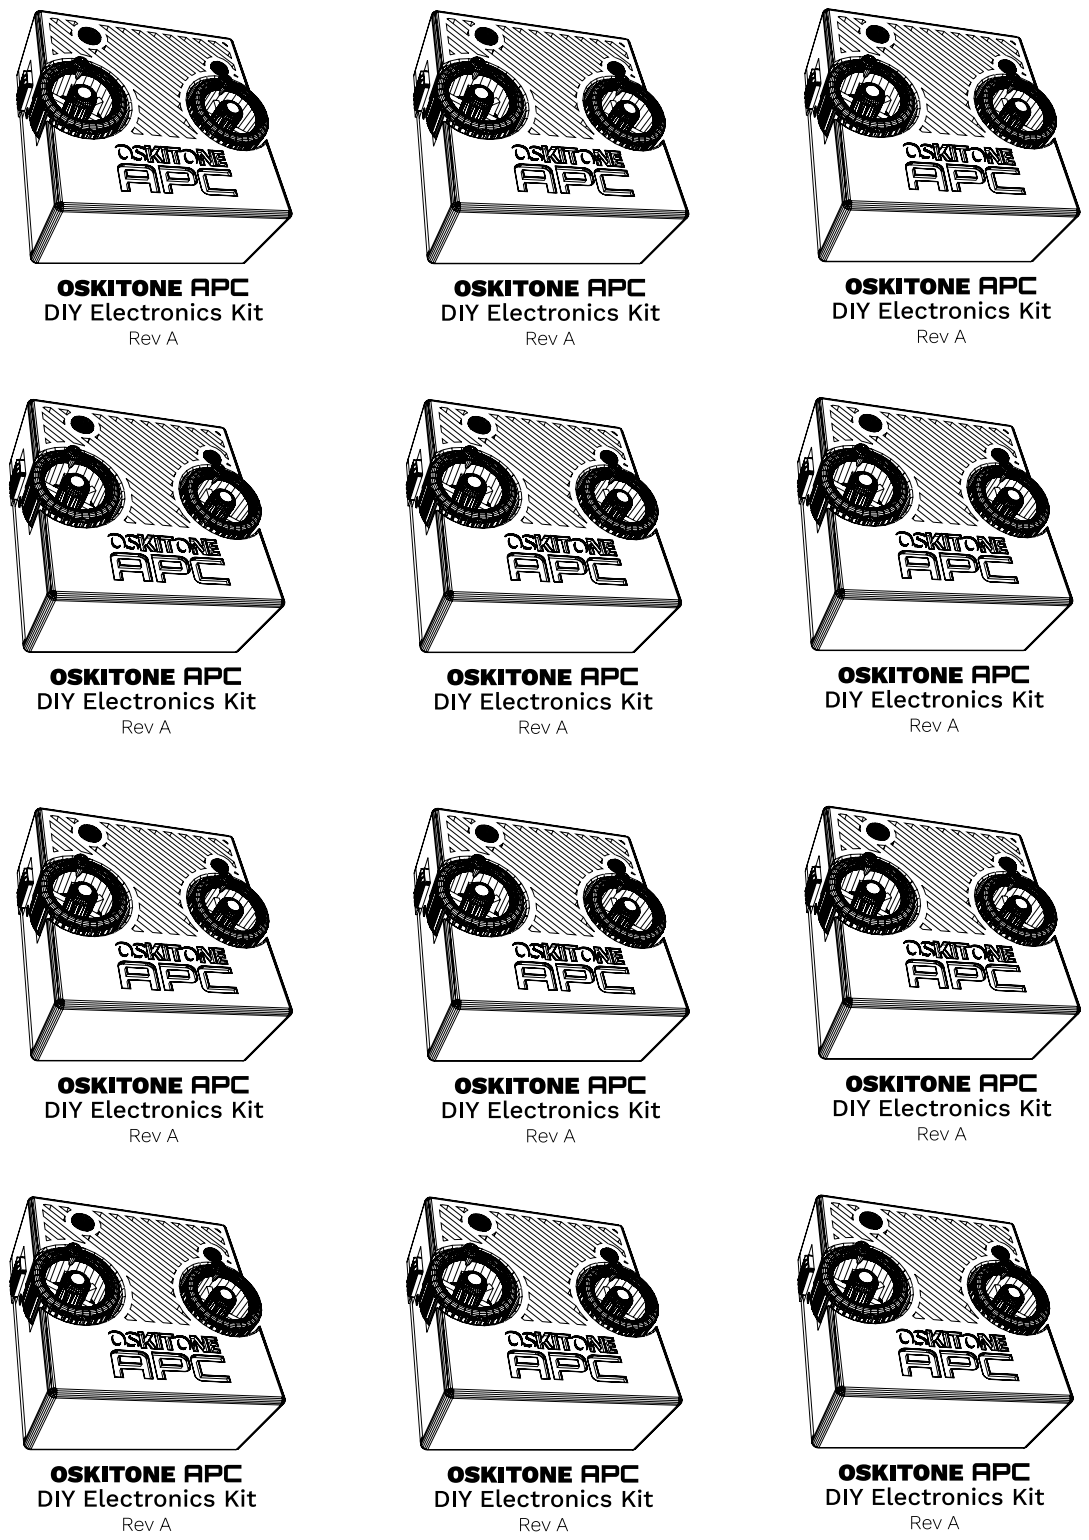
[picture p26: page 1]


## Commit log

2021-02-03 Add quick PCB svg and module
    [pcb.scad]
2021-02-04 Add quick battery module
    [battery.scad]
2021-02-04 Include misc components on PCB
    [pcb.scad]
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2021-02-04 Start exposing PCB components in newly filleted enclosure
    [enclosure.scad, pcb.scad]
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2021-02-04 Add inner walls around exposed components
    [enclosure.scad, pcb.scad]
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2021-02-04 Parameterize showing PCB board
    [pcb.scad]
2021-02-04 Parameterize showing wheels and switch actuator
    Honestly, they should be extracted from enclosure but that's not
    straightforward rn
    [enclosure.scad]
2021-02-04 Extract PCB xy and half heights
    [enclosure.scad]
2021-02-04 Fillet and rib switch actuator
    [enclosure.scad]
2021-02-04 Start cavity for switch actuator
    [enclosure.scad, pcb.scad]
2021-02-05 Fix and extract switch actuator Y
    [enclosure.scad, pcb.scad]
2021-02-05 Add support wall for actuator
    [enclosure.scad]
2021-02-05 Extract and tidy switch and web stuff
    * Extract tolerance, exposure, some (tentatively named) exposed_switch_*
    * Fix web obstructing into switch base from misapplied tolerance
    [enclosure.scad]
2021-02-05 Rename exposed_switch_actuator to switch_clutch
    noun
    noun: clutch; plural noun: clutches
    1.
    a tight grasp or an act of grasping something.
    "she made a clutch at his body"
    [enclosure.scad]
2021-02-05 Extract shared constants, wheels
    [enclosure.scad, shared_constants.scad, wheels.scad]
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2021-02-05 Decouple enclosure and assembly
    and some related extraction nitfixes...
    Dependencies are still a little blurry, but at least now I think stuff
    is relatively well organized.
    [assembly.scad, enclosure.scad, shared_constants.scad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]
2021-02-06 Refine accent
    * Intersect with diagonal grill
    * Parameterize depth, coverage
    * Ring around exposed LED and pots
    * Cover speaker
    [enclosure.scad]
2021-02-06 Stub cross section intersection
    [assembly.scad]
2021-02-06 Oh! Enclosure is taller than battery
    [assembly.scad, enclosure.scad]
2021-02-06 Remove redundant enclosure constants
    [enclosure.scad, shared_constants.scad]
2021-02-06 Decouple gutter(s)
    * Rename ENCLOSURE_GUTTER to ENCLOSURE_INTERNAL_GUTTER
    * With that rename, it's obvious that the grill shouldn't rely on it,
    so parameterize that out
    * And do the same for the gril rings, which look nicer thinner
    [assembly.scad, enclosure.scad, shared_constants.scad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]
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2021-02-06 Fix switch cltch vs pot whee wall obstruction
    by subtracting the wall cylinders from the clutch
    [assembly.scad, enclosure.scad, shared_constants.scad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]
2021-02-08 Enable animating enclosure slide
    [assembly.scad, enclosure.scad]
2021-02-08 Minimize PCB Z
    and fix thing where it didn't include floor as expected
    [assembly.scad, shared_constants.scad]
2021-02-08 Add pot shaft holes
    [enclosure.scad]
2021-02-08 Measure stuff IRL
    Shock!
    [pcb.scad]
2021-02-08 Wall internal pot shaft beyond well
    [assembly.scad, enclosure.scad, pcb.scad]
2021-02-08 Try to standardize $fn
    with values borrowed from POLY555
    [enclosure.scad, shared_constants.scad]
2021-02-08 Try to DFM well cavities
    [enclosure.scad, shared_constants.scad]
2021-02-08 Extend make_stls to make enclosure pieces
    [assembly.scad]
2021-02-08 Only show DFM when making STLs
    [assembly.scad, enclosure.scad]
2021-02-08 Try to DFM switch clutch
    [switch_clutch.scad]
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2021-02-08 Fix enclosure bottom height against PCB
    [shared_constants.scad]
2021-02-08 Add hella TODOs from test print
    [enclosure.scad, pcb.scad, switch_clutch.scad]
2021-02-08 Extract pot() from pcb()
    and extend for cavity usage
    [pcb.scad]
2021-02-08 Refine wheel, version 1
    [wheels.scad]
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2021-02-09 Refine wheel
    * Drop to prescribed height
    * Round bottom edge
    * Rib like switch clutch
    * Round hub cap
    * Try w/o brodie knob
    This takes FOREVER to render (⇀‸↼‶)
    [shared_constants.scad, switch_clutch.scad, wheels.scad]
2021-02-09 Increase wheel clearance
    [enclosure.scad, wheels.scad]
2021-02-09 Try to cut down on LED light bleed
    [assembly.scad, enclosure.scad]
2021-02-09 Increase switch clutch clearance
    [assembly.scad, enclosure.scad, shared_constants.scad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]
2021-02-09 Fix LED wall being too tight
    [enclosure.scad, pcb.scad]
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2021-02-09 Increase and visualize PCB clearance
    [pcb.scad]
2021-02-09 Fix battery Z
    Still needs support but at least not floating...
    [assembly.scad]
2021-02-09 Fix wheel well walls
    [enclosure.scad, wheels.scad]
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2021-02-10 Flip enclosure top STL
    [assembly.scad]
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2021-02-10 Measure and refine switch base height
    Shouldn't matter much since the difference is well within the clutch's
    vertical clearance.
    And add clarifying comment about clutch height
    [pcb.scad, switch_clutch.scad]
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2021-02-10 Thicken wheel ring
    Now the radius will match the enclosure, which might be nice?
    Whatever the case, ENCLOSURE_WALL isn't visible so didn't make sense to
    use that
    [wheels.scad]
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2021-02-11 De-obstruct PCB leads from enclosure lip
    Requires APC-related changes in poly555 repo
    [assembly.scad, shared_constants.scad]
2021-02-11 Fix errant LED ring
    [enclosure.scad]
2021-02-11 fixup! De-obstruct PCB leads from enclosure lip
    [enclosure.scad, shared_constants.scad]
2021-02-11 Tighten pot cavities
    Trying to cut down on wiggling...
    [enclosure.scad]
2021-02-11 Refine wheels
    * Vertically expose
    * Bring back and increase but minimize brodie knobs
    * Drop spokes height a bit
    [assembly.scad, enclosure.scad, wheels.scad]
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2021-02-11 Try tightening up well DFM
    [enclosure.scad]
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2021-02-12 Optimize wheel rendering time
    * Introduce fixed low rounding for small, low importance values like
    rib cavities
    * Default to default rounding for wheel and only use hidef for the
    pot cavity
    * Remove some render()s to speed up initial preview during development
    [shared_constants.scad, wheels.scad]
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2021-02-12 For real, only output 1 wheel in STL
    [assembly.scad, wheels.scad]
2021-02-12 Fix unconnected spoke at wheel bottom
    [wheels.scad]
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2021-02-12 Refine brodie knob
    * Only one for obvious marker
    * Taller for better grip
    * At bottom instead of top?
    [wheels.scad]
2021-02-13 Refine how switch clutch is held into enclosure
    Support its full web, which should feel better
    [enclosure.scad, switch_clutch.scad]
2021-02-13 Refine switch clutch
    * Add skirt to hide PCB
    * Make clutch vertical clearances match
    * Use breakaway supports and 45def chamfer
    [assembly.scad, shared_constants.scad, switch_clutch.scad]
2021-02-13 Try a thunkyboi design
    * Rotate battery
    * Extract GRILL_LENGTH
    * Increase grill depth, gutter, ring, and coverage
    * Semi-smartly adjust enclosure height to battery
    [battery.scad, enclosure.scad, shared_constants.scad]
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2021-02-13 Revert "Try tightening up well DFM"
    This reverts commit dc0fd64e149e56760f62669407d92e8c26bba774.
    This just made a mess!
    [enclosure.scad]
2021-02-13 Fix volume exposure preview
    [enclosure.scad]
2021-02-13 Improve enclosure top preview
    Those grill cavities are expensive!
    [enclosure.scad]
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2021-02-14 Refine brand engraving
    aka account for tolerance
    [enclosure.scad]
2021-02-14 Increase battery snap clearance
    Worried about straining those wires
    [battery.scad, shared_constants.scad]
2021-02-14 Widen volume pot access
    WFM but maybe not other screwdrivers
    [pcb.scad]
2021-02-14 Loosen switch clutch wall fit
    Ideally this wall only holds switch in place before PCB is inserted.
    Otherwise switch is to hard to toggle.
    It's possible this is too loose!
    [enclosure.scad, switch_clutch.scad]
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2021-02-15 Fix speaker vs wheel cavity collision
    Speaker cavity was previously cutting into the wells', creating holes
    in the enclosure top, and messing up the DFM layer.
    Turns out the speaker cavity needn't be the whole diameter for its full
    height. Narrowing it towards the top prevents collision and won't impede
    any sound.
    [enclosure.scad, pcb.scad]
2021-02-15 Rename assembly to apc\n\nI have too many assembly files
    [apc.scad]
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2021-02-16 Fix exposed, big inner grill
    [enclosure.scad]
2021-02-16 Fix speaker cavity preview
    [enclosure.scad]
2021-02-16 Try to fix speaker vs wheel cavities
    Wheel well walls weren't thick enough for DFM, probably caused by
    the speaker cavity.
    Hopefully receding the wheel walls into the speaker cavity provides
    more room for DFM bridges to take hold.
    [enclosure.scad]
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2021-02-16 Chamfer holes
    to mitigate elephant foot on wheel cavities
    [enclosure.scad]
2021-02-16 Remake DFM supports for switch clutch
    Seems to work just fine, just fine, thank you
    [switch_clutch.scad]
2021-02-16 Work around intersection() bug in OpenSCAD 2021.01
    [apc.scad]
2021-02-17 Remove vestigial include_tongue_and_groove arg
    Relies on commit e456694a8b in poly555
    [enclosure.scad]
2021-02-17 Try straight inner speaker grill
    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
    [enclosure.scad]
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2021-02-19 Fix 0 knob count bug
    [wheels.scad]
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2021-02-19 Try to prevent loose hanging filament on switch clutch
    [switch_clutch.scad]
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2021-02-19 Increase wheel clearance and chamfer
    [enclosure.scad, wheels.scad]
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2021-02-22 Don't derive wheel height
    No physical changes. But now that wheel height isn't derived from
    flatted pot measurements, it may as well be a fixed constant.
    [shared_constants.scad, wheels.scad]
2021-02-22 Add debugger info for enclosure vs wheel
    Echo dimensions, add wheel cross section
    [apc.scad, cross_section.scad]
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2021-02-22 Increase PCB clearance
    [pcb.scad]
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2021-02-23 Try to fix speaker vs wheel cavity collision again
    Reverts 7768ce125e, which caused the speaker to no longer perfectly fit
    into its cavity.
    Additionally, instead of having the two things fight, this change tries
    to find room somewhere else by reducing the side exposure just a lilbit.
    AND adds a cross section to debug
    [cross_section.scad, enclosure.scad, shared_constants.scad]
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2021-02-24 Fix PCB rail height vs enclosure bottom height
    The extra clearance from d7a50cb1dc left a 1mm gap between the PCB
    and its rails.
    * Accounts for that clearance in the enclosure bottom height, which is
    used for the rail height
    * Fixes const redundancies and a cross_section typo
    * Puts that 1mm difference on the top endstop
    [cross_section.scad, enclosure.scad, shared_constants.scad]
2021-02-26 Refine wheels
    * Fix floating wheel chamfer wall
    * Reduce exposed height to match switch
    * Extract ring and match for brodie knob
    [wheels.scad]
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2021-06-01 Fix overzealous wheel cavity height
    Now hub_ceiling = 0 actually does what you'd expect
    [wheels.scad]
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2021-09-07 Loosen wheel fit
    I worry that the extra tight fit was requiring too much force to
    assemble and inadvertently damaging the pots.
    This change is intentionally done on PTV09A_POT_ACTUATOR_DIAMETER to be
    agnostic to tolerance
    [pcb.scad]
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2022-08-23 Link to printables.com for downloads
    * Swap URL
    * Ditch custom downloads site
    (worked fine but I want that URL for other stuff)
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
